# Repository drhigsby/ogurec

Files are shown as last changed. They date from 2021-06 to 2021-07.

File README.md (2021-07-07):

# ogurec
A 12u X 3u reversible ortholinear keyborb

Left-sided PM = components away from PCB

Right-sided PM = components towards PCB

http://www.keyboard-layout-editor.com/#/gists/f1bda3a87822868599cf6e3c4340f594

Ogurec (Огурец) means 'Cucumber' in Russian. The name is a play on 'Gherkin', a 3x10 board, because the 3x12 layout supports all the letter keys of Jcuken (Russian equivalent of qwerty) unlike the 30-keyed Gherkin.

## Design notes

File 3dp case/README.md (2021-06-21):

# ogurec

required hardware

8x M2 4mm x 3.5mm press fit threaded inserts:
https://www.amazon.com/dp/B07VBRF7P2?psc=1&ref=ppx_yo2_dt_b_product_details

8x M2 x 5mm screws:
https://www.amazon.com/gp/product/B07HGNNQGJ/ref=ppx_yo_dt_b_asin_title_o02_s00?ie=UTF8&psc=1

case creator: Glow https://github.com/dpalka15

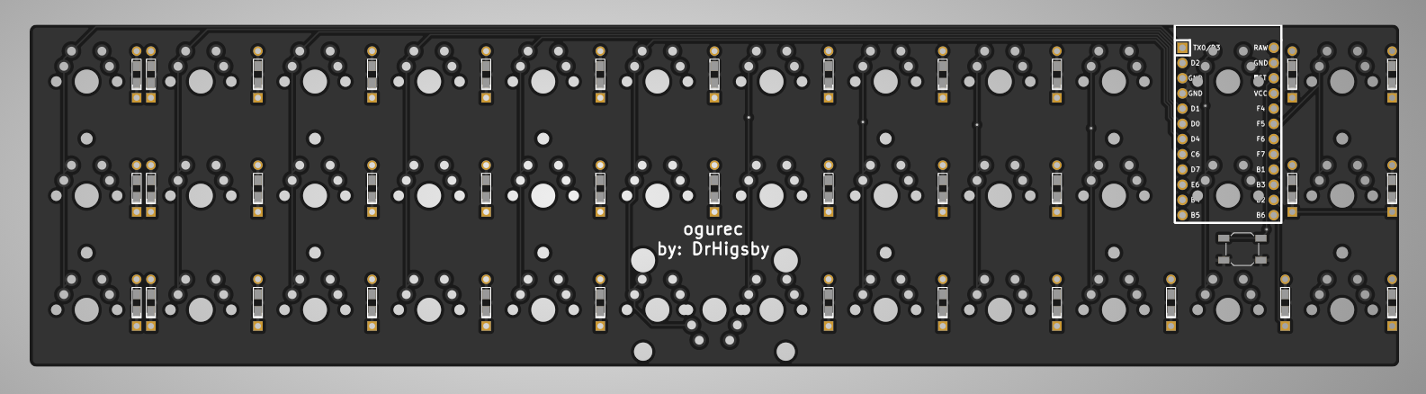
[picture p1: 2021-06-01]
ogurec.png

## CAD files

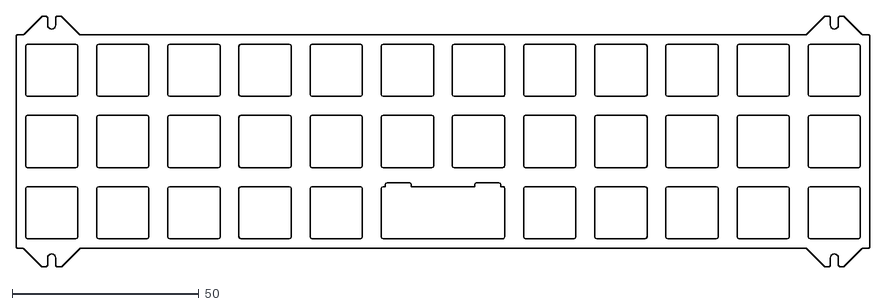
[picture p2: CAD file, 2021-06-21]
3dp case/OgurecPlate.dxf
228.6 x 67.2

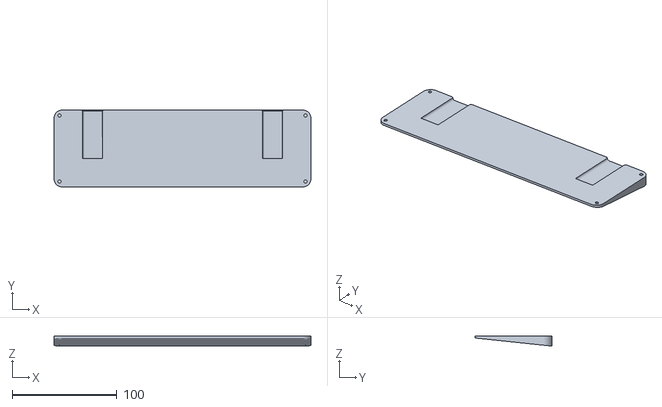
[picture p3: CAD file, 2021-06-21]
3dp case/OgurecBottom.stl
244.9 x 73.4 x 9.72

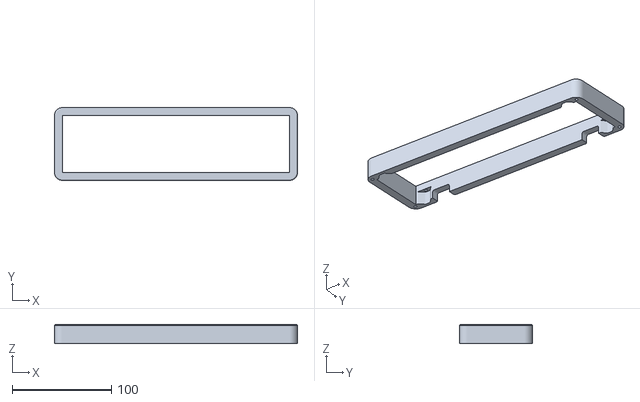
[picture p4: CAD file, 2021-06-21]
3dp case/OgurecTop.stl
244.9 x 73.4 x 19.6

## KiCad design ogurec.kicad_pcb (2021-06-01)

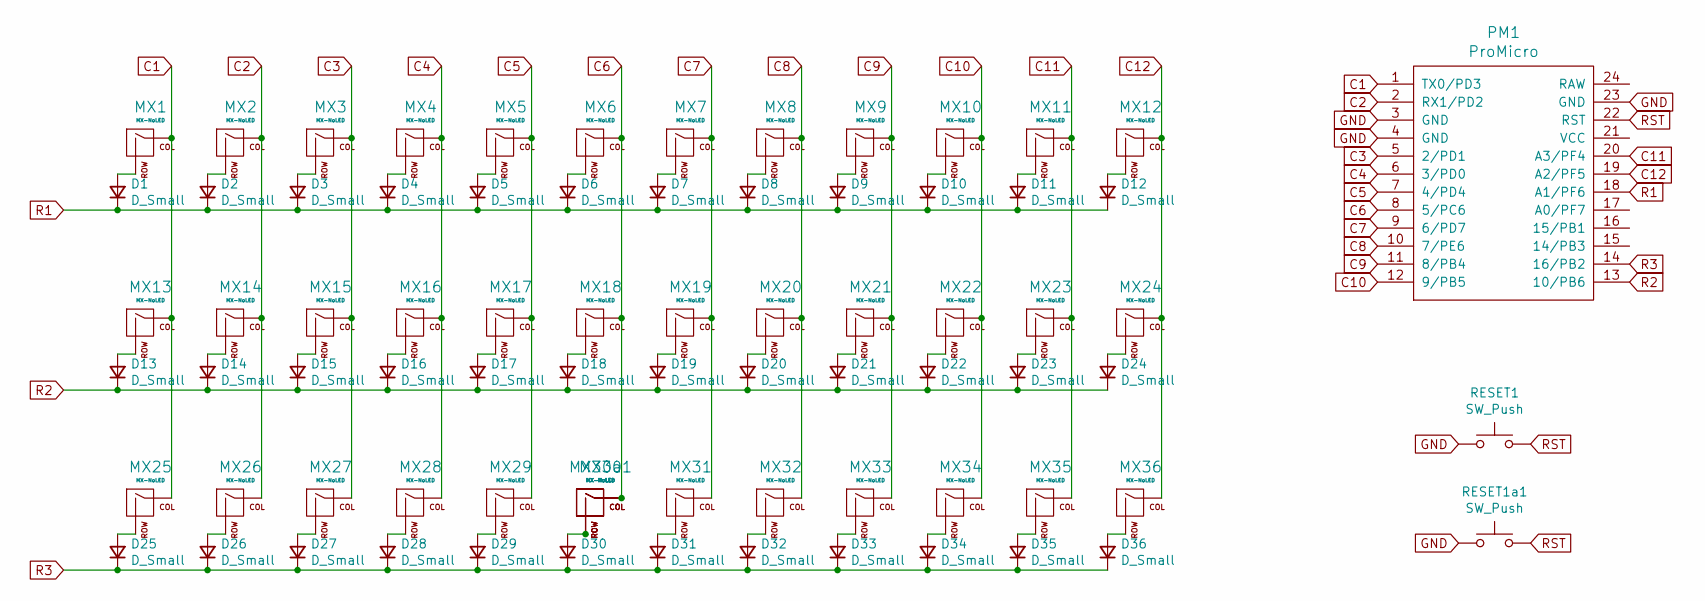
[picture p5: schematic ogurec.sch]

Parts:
D1, D2, D3, D4, D5, D6, D7, D8, D9, D10, D11, D12, D13, D14, D15, D16, D17, D18, D19, D20, D21, D22, D23, D24, D25, D26, D27, D28, D29, D30, D31, D32, D33, D34, D35, D36: D_Small; Diode-dual
MX1, MX2, MX3, MX4, MX5, MX6, MX7, MX8, MX9, MX10, MX11, MX12, MX13, MX14, MX15, MX16, MX17, MX18, MX19, MX20, MX21, MX22, MX23, MX24, MX25, MX26, MX27, MX28, MX29, MX30, MX31, MX32, MX33, MX34, MX35, MX36: MX-NoLED; MX_ONLY_1u_NOLED_REVERSIBLE
MX30a1: MX-NoLED; MXOnly-2U-NoLED-REVERSIBLE
PM1: ProMicro; ArduinoProMicro
RESET1, RESET1a1: SW_Push; SW_SPST_SKQG_WithoutStem

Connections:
C1: MX1.1 (COL), MX13.1 (COL), MX25.1 (COL), PM1.1 (TX0/PD3)
C2: MX2.1 (COL), MX14.1 (COL), MX26.1 (COL), PM1.2 (RX1/PD2)
C3: MX3.1 (COL), MX15.1 (COL), MX27.1 (COL), PM1.5 (2/PD1)
C4: MX4.1 (COL), MX16.1 (COL), MX28.1 (COL), PM1.6 (3/PD0)
C5: MX5.1 (COL), MX17.1 (COL), MX29.1 (COL), PM1.7 (4/PD4)
C6: MX6.1 (COL), MX18.1 (COL), MX30.1 (COL), MX30a1.1 (COL), PM1.8 (5/PC6)
C7: MX7.1 (COL), MX19.1 (COL), MX31.1 (COL), PM1.9 (6/PD7)
C8: MX8.1 (COL), MX20.1 (COL), MX32.1 (COL), PM1.10 (7/PE6)
C9: MX9.1 (COL), MX21.1 (COL), MX33.1 (COL), PM1.11 (8/PB4)
C10: MX10.1 (COL), MX22.1 (COL), MX34.1 (COL), PM1.12 (9/PB5)
C11: MX11.1 (COL), MX23.1 (COL), MX35.1 (COL), PM1.20 (A3/PF4)
C12: MX12.1 (COL), MX24.1 (COL), MX36.1 (COL), PM1.19 (A2/PF5)
GND: PM1.3 (GND), PM1.4 (GND), PM1.23 (GND), RESET1.1, RESET1a1.1
unnamed: D1.2 (A), MX1.2 (ROW)
unnamed: D2.2 (A), MX2.2 (ROW)
unnamed: D3.2 (A), MX3.2 (ROW)
unnamed: D4.2 (A), MX4.2 (ROW)
unnamed: D5.2 (A), MX5.2 (ROW)
unnamed: D6.2 (A), MX6.2 (ROW)
unnamed: D7.2 (A), MX7.2 (ROW)
unnamed: D8.2 (A), MX8.2 (ROW)
unnamed: D9.2 (A), MX9.2 (ROW)
unnamed: D10.2 (A), MX10.2 (ROW)
unnamed: D11.2 (A), MX11.2 (ROW)
unnamed: D12.2 (A), MX12.2 (ROW)
unnamed: D13.2 (A), MX13.2 (ROW)
unnamed: D14.2 (A), MX14.2 (ROW)
unnamed: D15.2 (A), MX15.2 (ROW)
unnamed: D16.2 (A), MX16.2 (ROW)
unnamed: D17.2 (A), MX17.2 (ROW)
unnamed: D18.2 (A), MX18.2 (ROW)
unnamed: D19.2 (A), MX19.2 (ROW)
unnamed: D20.2 (A), MX20.2 (ROW)
unnamed: D21.2 (A), MX21.2 (ROW)
unnamed: D22.2 (A), MX22.2 (ROW)
unnamed: D23.2 (A), MX23.2 (ROW)
unnamed: D24.2 (A), MX24.2 (ROW)
unnamed: D25.2 (A), MX25.2 (ROW)
unnamed: D26.2 (A), MX26.2 (ROW)
unnamed: D27.2 (A), MX27.2 (ROW)
unnamed: D28.2 (A), MX28.2 (ROW)
unnamed: D29.2 (A), MX29.2 (ROW)
unnamed: D30.2 (A), MX30.2 (ROW), MX30a1.2 (ROW)
unnamed: D31.2 (A), MX31.2 (ROW)
unnamed: D32.2 (A), MX32.2 (ROW)
unnamed: D33.2 (A), MX33.2 (ROW)
unnamed: D34.2 (A), MX34.2 (ROW)
unnamed: D35.2 (A), MX35.2 (ROW)
unnamed: D36.2 (A), MX36.2 (ROW)
R1: D1.1 (K), D2.1 (K), D3.1 (K), D4.1 (K), D5.1 (K), D6.1 (K), D7.1 (K), D8.1 (K), D9.1 (K), D10.1 (K), D11.1 (K), D12.1 (K), PM1.18 (A1/PF6)
R2: D13.1 (K), D14.1 (K), D15.1 (K), D16.1 (K), D17.1 (K), D18.1 (K), D19.1 (K), D20.1 (K), D21.1 (K), D22.1 (K), D23.1 (K), D24.1 (K), PM1.13 (10/PB6)
R3: D25.1 (K), D26.1 (K), D27.1 (K), D28.1 (K), D29.1 (K), D30.1 (K), D31.1 (K), D32.1 (K), D33.1 (K), D34.1 (K), D35.1 (K), D36.1 (K), PM1.14 (16/PB2)
RST: PM1.22 (RST), RESET1.2, RESET1a1.2

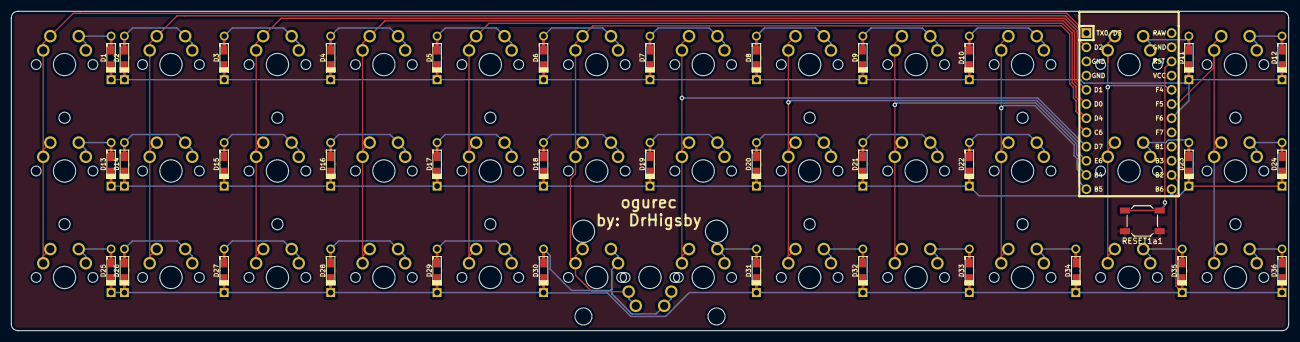
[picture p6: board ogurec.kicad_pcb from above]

Board: 2 copper layers, 228.6 x 57.2 mm, 76 parts (1 on the bottom side), 53 nets.

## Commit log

2021-06-01 Reversible PCB update
    Reversible PCB update
    [dakkadakka-B_Cu.gbr, dakkadakka-B_Mask.gbr, dakkadakka-B_Paste.gbr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]
2021-06-01 updated pcb render
    updated pcb render
2021-06-01 ogurec name change
    ogurec name change
    [dakkadakka-B_Cu.gbr, dakkadakka-B_Mask.gbr, dakkadakka-B_Paste.gbr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]
2021-06-21 removing individual pcb gerbers (they are in a zip)
    [ogurec-B_Cu.gbr, ogurec-B_Mask.gbr, ogurec-B_Paste.gbr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]
2021-06-21 adding 3dp files (made by Glow)
    [OgurecBottom.stl, OgurecTop.stl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]
2021-06-21 added 3dp case readme
